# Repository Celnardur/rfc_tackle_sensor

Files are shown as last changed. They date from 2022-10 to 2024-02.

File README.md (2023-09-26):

# Collegiate Robotic Football Tackle Sensor Hardware

## Cloning the Repo

Open a git bash terminal in the directory of your choosing and call the following command:

`git clone https://github.com/Celnardur/rfc_tackle_sensor.git`

## Developing

This project was created using KiCad v6.  This must be installed prior to editing the project.

## Additional Links

- The firmware for the sensor can be found here: https://github.com/ehunck/rfc_tackle_sensor_firmware
- An example web-serial configuration utility can be found here: https://github.com/ehunck/tackle-sensor-utility

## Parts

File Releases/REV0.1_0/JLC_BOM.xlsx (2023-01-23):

Comment | Designator | Footprint | JLCPCB Part #（optional） | Quantity | MPN | Unit Price (@ qty 100) | Device Price
100nF, 50V | C1, C3, C4, C9, C13, C14 | Capacitor_SMD:C_0805_2012Metric | C49678 | 6 | CC0805KRX7R9BB104 | 0.0038 | 0.0228
10uF, 50V | C2, C15 | Capacitor_SMD:CP_Elec_6.3x5.8 | C308830 | 2 | UUD1H100MCL1GS | 0.0818 | 0.1636
2200pF,10%,50V | C5 | Capacitor_SMD:C_0402_1005Metric | C338130 | 1 | 0402B222K500CT | 0.0011 | 0.0011
0.22uF,10%,35V | C6 | Capacitor_SMD:C_0402_1005Metric | C694490 | 1 | CGA2B1X7R1V224KT000F | 0.0338 | 0.0338
1uF, 50V | C7, C10, C11 | Capacitor_SMD:C_0603_1608Metric | C90540 | 3 | 0603B105K500NT | 0.0096 | 0.0288
1nF, 50V | C8 | Capacitor_SMD:C_0402_1005Metric | C1523 | 1 | 0402B102K500NT | 0.001 | 0.001
22uF, 20V | C12 | Capacitor_SMD:CP_Elec_6.3x5.9 | C215761 | 1 | 20SVP22M | 0.3975 | 0.3975
BZT52-B15_R1_00001 | D1 | Diode_SMD:D_SOD-123 | C188533 | 1 | BZT52-B15_R1_00001 | 0.0173 | 0.0173
DSK34 | D2 | Diode_SMD:D_SOD-123F | C41029 | 1 | DSK34 | 0.0282 | 0.0282
LED | D3 | LED_SMD:LED_0603_1608Metric | C72038 | 1 | 19-213/Y2C-CQ2R2L/3T(CY) | 0.0159 | 0.0159
CLV1A-FKB-CK1VW1DE1BB7C3C3 | D4 | LED_SMD:LED_Cree-PLCC4_3.2x2.8mm_CCW |  | 1 | CLV1A-FKB-CK1VW1DE1BB7C3C3 | 0.361 | 0.361
1210L075YR | F1 | Resistor_SMD:R_1210_3225Metric | C207046 | 1 | 1210L075YR | 0.1673 | 0.1673
Conn_ARM_JTAG_SWD_10 | J1 | rfc_footprint_lib:20021121-00010C4LF | C150517 | 1 | 20021121-00010C4LF | 0.7533 | 0.7533
Conn_01x02_Male | J2 | Connector_JST:JST_XH_B2B-XH-A_1x02_P2.50mm_Vertical | C158012 | 1 | B2B-XH-A(LF)(SN) | 0.0257 | 0.0257
Conn_01x03_Male | J3 | Connector_JST:JST_XH_B3B-XH-A_1x03_P2.50mm_Vertical | C144394 | 1 | B3B-XH-A(LF)(SN) | 0.027 | 0.027
Conn_01x04_Male | J4 | Connector_JST:JST_XH_B4B-XH-A_1x04_P2.50mm_Vertical | C144395 | 1 | B4B-XH-A(LF)(SN) | 0.0344 | 0.0344
DMP4051LK3 | Q1 | Package_TO_SOT_SMD:TO-252-2 | C397952 | 1 | DMP4051LK3-13 | 0.363 | 0.363
NCE0110K | Q2 | Package_TO_SOT_SMD:TO-252-2 | C95272 | 1 | NCE0110K | 0.1314 | 0.1314
10k,1%,63mW | R1, R3, R5, R9 | Resistor_SMD:R_0402_1005Metric | C25744 | 4 | 0402WGF1002TCE | 0.0006 | 0.0024
634,.1%,63mW | R2 | Resistor_SMD:R_0402_1005Metric | C2998183 | 1 | FRC0402F6340TS | 0.0005 | 0.0005
56.2k,1%,63mW | R4 | Resistor_SMD:R_0402_1005Metric | C54968 | 1 | 0402WGF5622TCE | 0.0005 | 0.0005
100,1%,63mW | R6 | Resistor_SMD:R_0402_1005Metric | C25076 | 1 | 0402WGF1000TCE | 0.0005 | 0.0005
25mOhm,1%,500mW | R7 | Resistor_SMD:R_1206_3216Metric | C160920 | 1 | RL12FTNR200 | 0.0122 | 0.0122
84.5k,1%,63mW | R8 | Resistor_SMD:R_0402_1005Metric | C100545 | 1 | CR0402FF8452G | 0.0005 | 0.0005
0,63mW | R10 | Resistor_SMD:R_0402_1005Metric | C106231 | 1 | RC0402FR-070RL | 0.0007 | 0.0007
1k,1%,25mW | R11, R12, R13, R14 | Resistor_SMD:R_0603_1608Metric | C21190 | 4 | 0603WAF1001T5E | 0.0005 | 0.002
0,0.5W | R15, R17, R19 | Resistor_SMD:R_1210_3225Metric | C620661 | 3 | 1210W2F1000T5E | 0.0099 | 0.0297
220,1%,63mW | R16, R18 | Resistor_SMD:R_0402_1005Metric | C25091 | 2 | 0402WGF2200TCE | 0.0005 | 0.001
PTS645SL43SMTR92 LFS | SW1 | Button_Switch_SMD:SW_SPST_PTS645 | C221875 | 1 | PTS645SL43SMTR92LFS | 0.0741 | 0.0741
SW_DPDT_x2 | SW2 | rfc_footprint_lib:SS-3235S-L3 | C381098 | 1 | SS-3235S-L3 | 0.0617 | 0.0617
DRQ125-330-R | T1 | rfc_footprint_lib:DRQ125-150-R |  | 1 | DRQ125-330-R | 1.0832 | 1.0832
STM32G031Fx | U1 | Package_SO:TSSOP-20_4.4x6.5mm_P0.65mm | C529334 | 1 | STM32G031F8P6 | 0.9705 | 0.9705
LM3488 | U2 | Package_SO:VSSOP-8_3.0x3.0mm_P0.65mm | C80773 | 1 | LM3488MM/NOPB | 0.9 | 0.9
LIS2DE12 | U3 | Package_LGA:LGA-12_2x2mm_P0.5mm | C155639 | 1 | LIS2DE12TR | 1.017 | 1.017
LD1117S33TR_SOT223 | U4 | Package_TO_SOT_SMD:SOT-223-3_TabPin2 | C86781 | 1 | LD1117S33TR | 0.1982 | 0.1982
ULN2003ADR | U5 | Package_SO:SOIC-16_3.9x9.9mm_P1.27mm | C7512 | 1 | ULN2003ADR | 0.0918 | 0.0918
 |  |  |  |  |  | Total Price 1 unit | 7.0196

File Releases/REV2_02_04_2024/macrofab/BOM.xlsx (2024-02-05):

Designator | Value | Footprint | Populate | MPN | Manufacturer | MPN | Manufacturer
C1 | 100nF, 50V | C_0805_2012Metric | 1 | CC0805KRX7R9BB104 | Yageo
C10 | 1uF, 50V | C_0603_1608Metric | 1 | CL10A105KB8NNNC | Samsung
C11 | 1uF, 50V | C_0603_1608Metric | 1 | CL10A105KB8NNNC | Samsung
C12 | 22uF, 20V | CP_Elec_6.3x5.9 | 1 | 20SVP22M | Panasonic
C13 | 100nF, 50V | C_0805_2012Metric | 1 | CC0805KRX7R9BB104 | Yageo
C14 | 100nF, 50V | C_0805_2012Metric | 1 | CC0805KRX7R9BB104 | Yageo
C15 | 10uF, 50V | CP_Elec_6.3x5.8 | 1 | UUD1H100MCL1GS | Nichicon
C2 | 10uF, 50V | CP_Elec_6.3x5.8 | 1 | UUD1H100MCL1GS | Nichicon
C3 | 100nF, 50V | C_0805_2012Metric | 1 | CC0805KRX7R9BB104 | Yageo
C4 | 100nF, 50V | C_0805_2012Metric | 1 | CC0805KRX7R9BB104 | Yageo
C5 | 2200pF,10%,50V | C_0402_1005Metric | 1 | 0402B222K500CT | Walsin Technologies
C6 | 0.22uF,10%,35V | C_0402_1005Metric | 1 | CGA2B1X7R1V224KT000F | TDK | CGA2B1X7R1V224K050BE | TDK
C7 | 1uF, 50V | C_0603_1608Metric | 1 | CL10A105KB8NNNC | Samsung
C8 | 1nF, 50V | C_0402_1005Metric | 1 | 0402B102K500NT | Knowles Acoustics | C1005X7R1H102K050BA | TDK
C9 | 100nF, 50V | C_0805_2012Metric | 1 | CC0805KRX7R9BB104 | Yageo
D1 | BZT52-B15_R1_00001 | D_SOD-123 | 1 | BZT52-B15_R1_00001 | Panjit
D2 | DSK34 | D_SOD-123F | 1 | SBA340AL_R1_00001 | Panjit
D3 | LED | LED_0603_1608Metric | 1 | B1911UY--20D000114U1930 | Harvatek
D4 | CLV1A-FKB-CK1VW1DE1BB7C3C3 | LED_Cree-PLCC4_3.2x2.8mm_CCW | 1 | CLV1A-FKB-CK1VW1DE1BB7C3C3 | Wolfspeed
F1 | 1210L075YR | R_1210_3225Metric | 1 | 1210L075YR | Littelfuse
FID1 | Fiducial | Fiducial_0.5mm_Mask1.5mm | 0
FID2 | Fiducial | Fiducial_0.5mm_Mask1.5mm | 0
FID3 | Fiducial | Fiducial_0.5mm_Mask1.5mm | 0
H1 | MountingHole | MountingHole_3.2mm_M3 | 0
H2 | MountingHole | MountingHole_3.2mm_M3 | 0
H3 | MountingHole | MountingHole_3.2mm_M3 | 0
H4 | MountingHole | MountingHole_3.2mm_M3 | 0
J1 | Conn_ARM_JTAG_SWD_10 | 20021121-00010C4LF | 1 | 20021121-00010C4LF | Amphenol Communications Solutions
J2 | Conn_01x02_Male | JST_XH_B2B-XH-A_1x02_P2.50mm_Vertical | 1 | B2B-XH-A | JST
J4 | Conn_01x04_Male | JST_XH_B4B-XH-A_1x04_P2.50mm_Vertical | 1 | B4B-XH-A | JST
J5 | Conn_01x06_Male | JST_XH_B6B-XH-A_1x06_P2.50mm_Vertical | 1 | B6B-XH-A | JST
Q1 | DMP4051LK3 | TO-252-2 | 1 | DMP4051LK3-13 | Diodes Inc.
Q2 | NCE0110K | TO-252-2 | 1 | NCE0110K | Wuxi | RFD3055LESM9A | onsemi
R1 | 10k,1%,63mW | R_0402_1005Metric | 1 | 0402WGF1002TCE | Royal Ohm | RC0402FR-0710KP | Yageo
R10 | 10k,1%,63mW | R_0402_1005Metric | 1 | 0402WGF1002TCE | Royal Ohm | RC0402FR-0710KP | Yageo
R11 | 1k,1%,25mW | R_0603_1608Metric | 1 | 0603WAF1001T5E | Royal Ohm | RNCP0603FTD1K00 | Stackpole Electronics
R12 | 1k,1%,25mW | R_0603_1608Metric | 1 | 0603WAF1001T5E | Royal Ohm | RNCP0603FTD1K00 | Stackpole Electronics
R13 | 1k,1%,25mW | R_0603_1608Metric | 1 | 0603WAF1001T5E | Royal Ohm | RNCP0603FTD1K00 | Stackpole Electronics
R14 | 1k,1%,25mW | R_0603_1608Metric | 1 | 0603WAF1001T5E | Royal Ohm | RNCP0603FTD1K00 | Stackpole Electronics
R15 | 0,0.5W | R_1210_3225Metric | 1 | 1210W2F1000T5E | Uniroyal | RMCF1210ZT0R00 | Stackpole Electronics
R16 | 220,1%,63mW | R_0402_1005Metric | 1 | 0402WGF2200TCE | Royal Ohm | RC0402FR-07220RL | Yageo
R17 | 0,0.5W | R_1210_3225Metric | 1 | 1210W2F1000T5E | Uniroyal | RMCF1210ZT0R00 | Stackpole Electronics
R18 | 220,1%,63mW | R_0402_1005Metric | 1 | 0402WGF2200TCE | Royal Ohm | RC0402FR-07220RL | Yageo
R19 | 0,0.5W | R_1210_3225Metric | 1 | 1210W2F1000T5E | Uniroyal | RMCF1210ZT0R00 | Stackpole Electronics
R2 | 634,.1%,63mW | R_0402_1005Metric | 1 | RC0402FR-07634RL | Yageo
R20 | 220,1%,63mW | R_0402_1005Metric | 1 | 0402WGF2200TCE | Royal Ohm | RC0402FR-07220RL | Yageo
R21 | 10k,1%,63mW | R_0402_1005Metric | 1 | 0402WGF1002TCE | Royal Ohm | RC0402FR-0710KP | Yageo
R22 | 100k,1%,63mW | R_0402_1005Metric | 1 | RT0402BRE07100KL | Yageo
R23 | 10k,1%,63mW | R_0402_1005Metric | 1 | 0402WGF1002TCE | Royal Ohm | RC0402FR-0710KP | Yageo
R24 | 220,1%,63mW | R_0402_1005Metric | 1 | 0402WGF2200TCE | Royal Ohm | RC0402FR-07220RL | Yageo
R25 | 220,1%,63mW | R_0402_1005Metric | 1 | 0402WGF2200TCE | Royal Ohm | RC0402FR-07220RL | Yageo
R3 | 10k,1%,63mW | R_0402_1005Metric | 1 | 0402WGF1002TCE | Royal Ohm | RC0402FR-0710KP | Yageo
R4 | 56.2k,1%,63mW | R_0402_1005Metric | 1 | RC0402FR-0756K2L | Yageo
R5 | 100k,1%,63mW | R_0402_1005Metric | 1 | RT0402BRE07100KL | Yageo
R6 | 100,1%,63mW | R_0402_1005Metric | 1 | 0402WGF1000TCE | Royal Ohm | RC0402FR-13100RL | Yageo
R7 | 25mOhm,1%,500mW | R_1206_3216Metric | 1 | CSR1206FK25L0 | Stackpole Electronics
R8 | 84.5k,1%,63mW | R_0402_1005Metric | 1 | RC0402FR-0784K5L | Yageo
R9 | 10k,1%,63mW | R_0402_1005Metric | 1 | 0402WGF1002TCE | Royal Ohm | RC0402FR-0710KP | Yageo
S1 | DS01-254-L-02BE | SW_DS01-254-L-02BE | 1 | DS01-254-L-02BE | CUI Devices
SW1 | PTS645SL43SMTR92 LFS | SW_SPST_PTS645 | 1 | PTS645SL43SMTR92LFS | C&K Components
T1 | DRQ125-330-R | DRQ125-150-R | 1 | DRQ125-330-R | Eaton
TP1 | TestPoint | TestPoint_Pad_D1.0mm | 0
TP10 | TestPoint | test_point | 0
TP11 | TestPoint | test_point | 0
TP12 | TestPoint | TestPoint_Pad_D1.0mm | 0
TP13 | TestPoint | test_point | 0
TP14 | TestPoint | test_point | 0
TP15 | TestPoint | TestPoint_Pad_D1.0mm | 0
TP2 | TestPoint | test_point | 0
TP3 | TestPoint | TestPoint_Pad_D1.0mm | 0
TP8 | TestPoint | test_point | 0
TP9 | TestPoint | test_point | 0
U1 | STM32G031Fx | TSSOP-20_4.4x6.5mm_P0.65mm | 1 | STM32G031F8P6 | STMicroelectronics
U2 | LM3488 | VSSOP-8_3.0x3.0mm_P0.65mm | 1 | LM3488MM/NOPB | Texas Instruments
U3 | LIS2DE12 | LGA-12_2x2mm_P0.5mm | 1 | LIS2DE12TR | STMicroelectronics
U4 | LD1117S33TR_SOT223 | SOT-223-3_TabPin2 | 1 | LD1117S33TR | STMicroelectronics
U5 | ULN2003ADR | SOIC-16_3.9x9.9mm_P1.27mm | 1 | ULN2003ADR | Texas Instruments

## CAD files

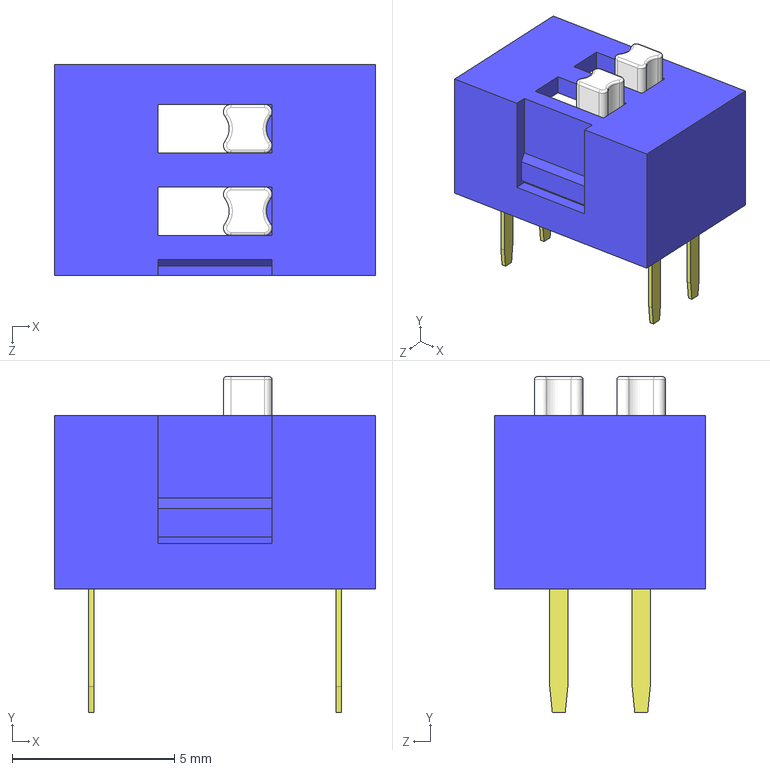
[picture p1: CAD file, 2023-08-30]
CUI_DEVICES_DS01-254-L-02BE.step
9.90 x 10.4 x 6.50 mm

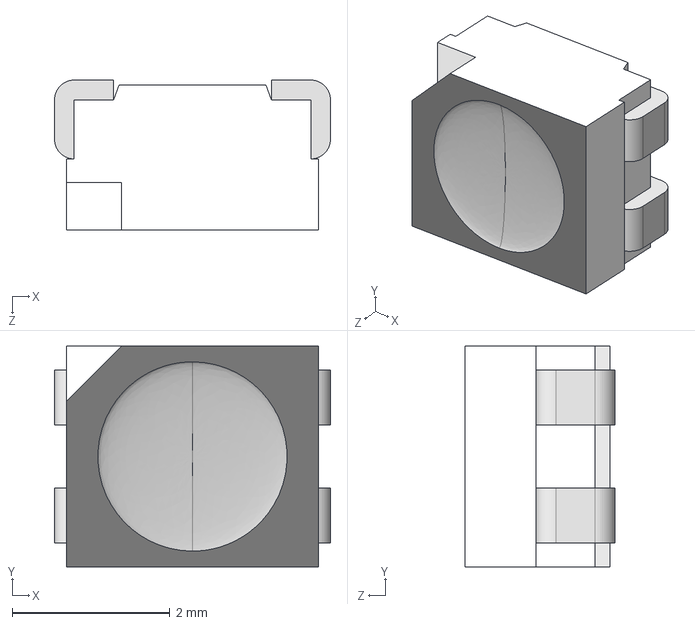
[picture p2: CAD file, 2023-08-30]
PLCC4_SMD_LED.STEP
3.50 x 2.80 x 1.90 mm

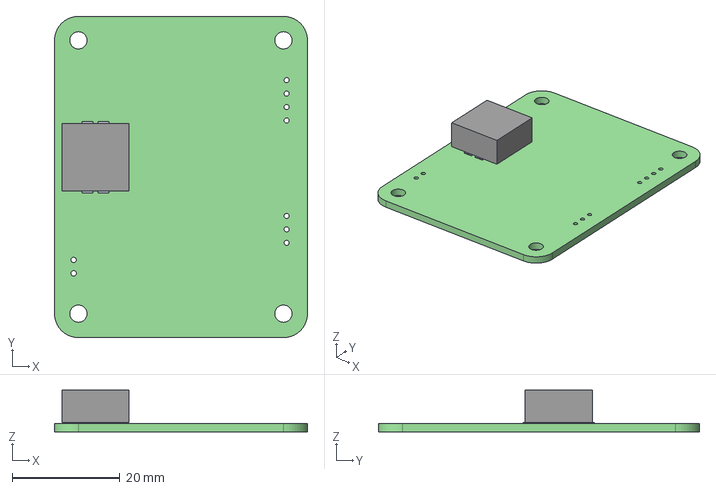
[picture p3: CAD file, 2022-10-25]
tackle_sensor_hardware.step
47.0 x 59.7 x 7.74 mm
tackle_sensor_hardware PCB

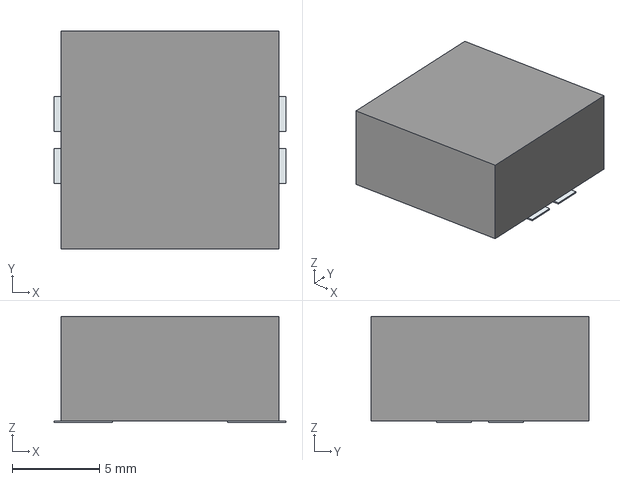
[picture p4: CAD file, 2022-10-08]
DRQ125-330-R.stp
13.3 x 12.5 x 6.10 mm
Pins

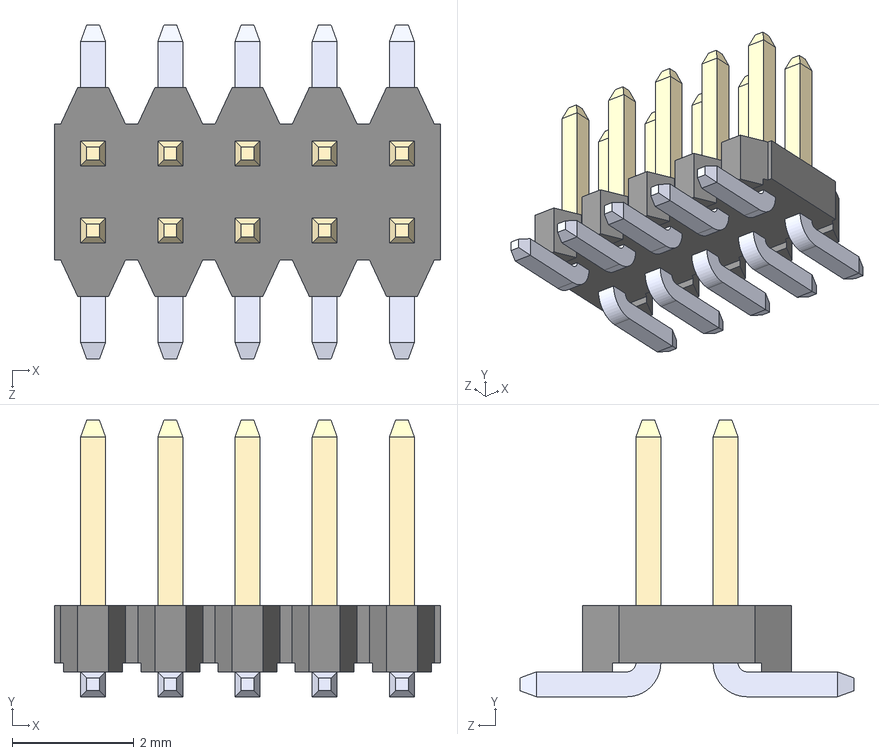
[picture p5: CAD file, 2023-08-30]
20021121-00010C4LF--3DModel-STEP-56544.STEP
6.35 x 4.55 x 5.50 mm
20021121-additional body-goldtin_5
Pin^20021121-additional-goldtin x 5

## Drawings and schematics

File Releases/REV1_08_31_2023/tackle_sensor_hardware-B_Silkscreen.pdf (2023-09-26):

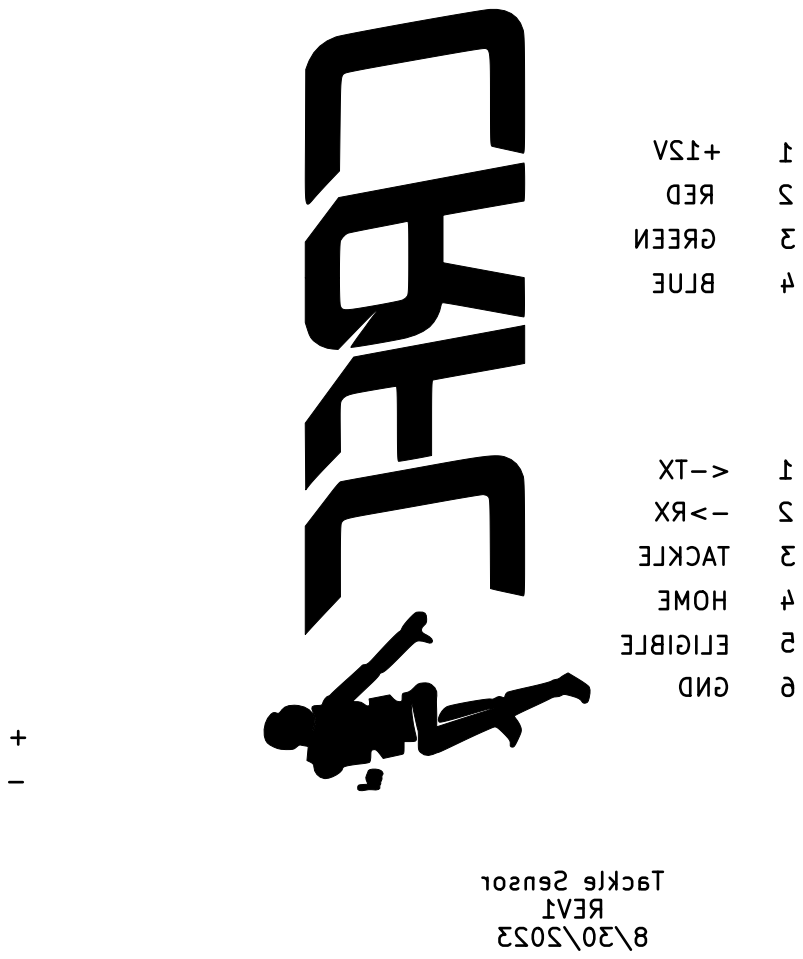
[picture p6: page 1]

8/30/2023 3 TACKLE 63 +- 2 +12V GREEN 24 ELIGIBLE 51 RED

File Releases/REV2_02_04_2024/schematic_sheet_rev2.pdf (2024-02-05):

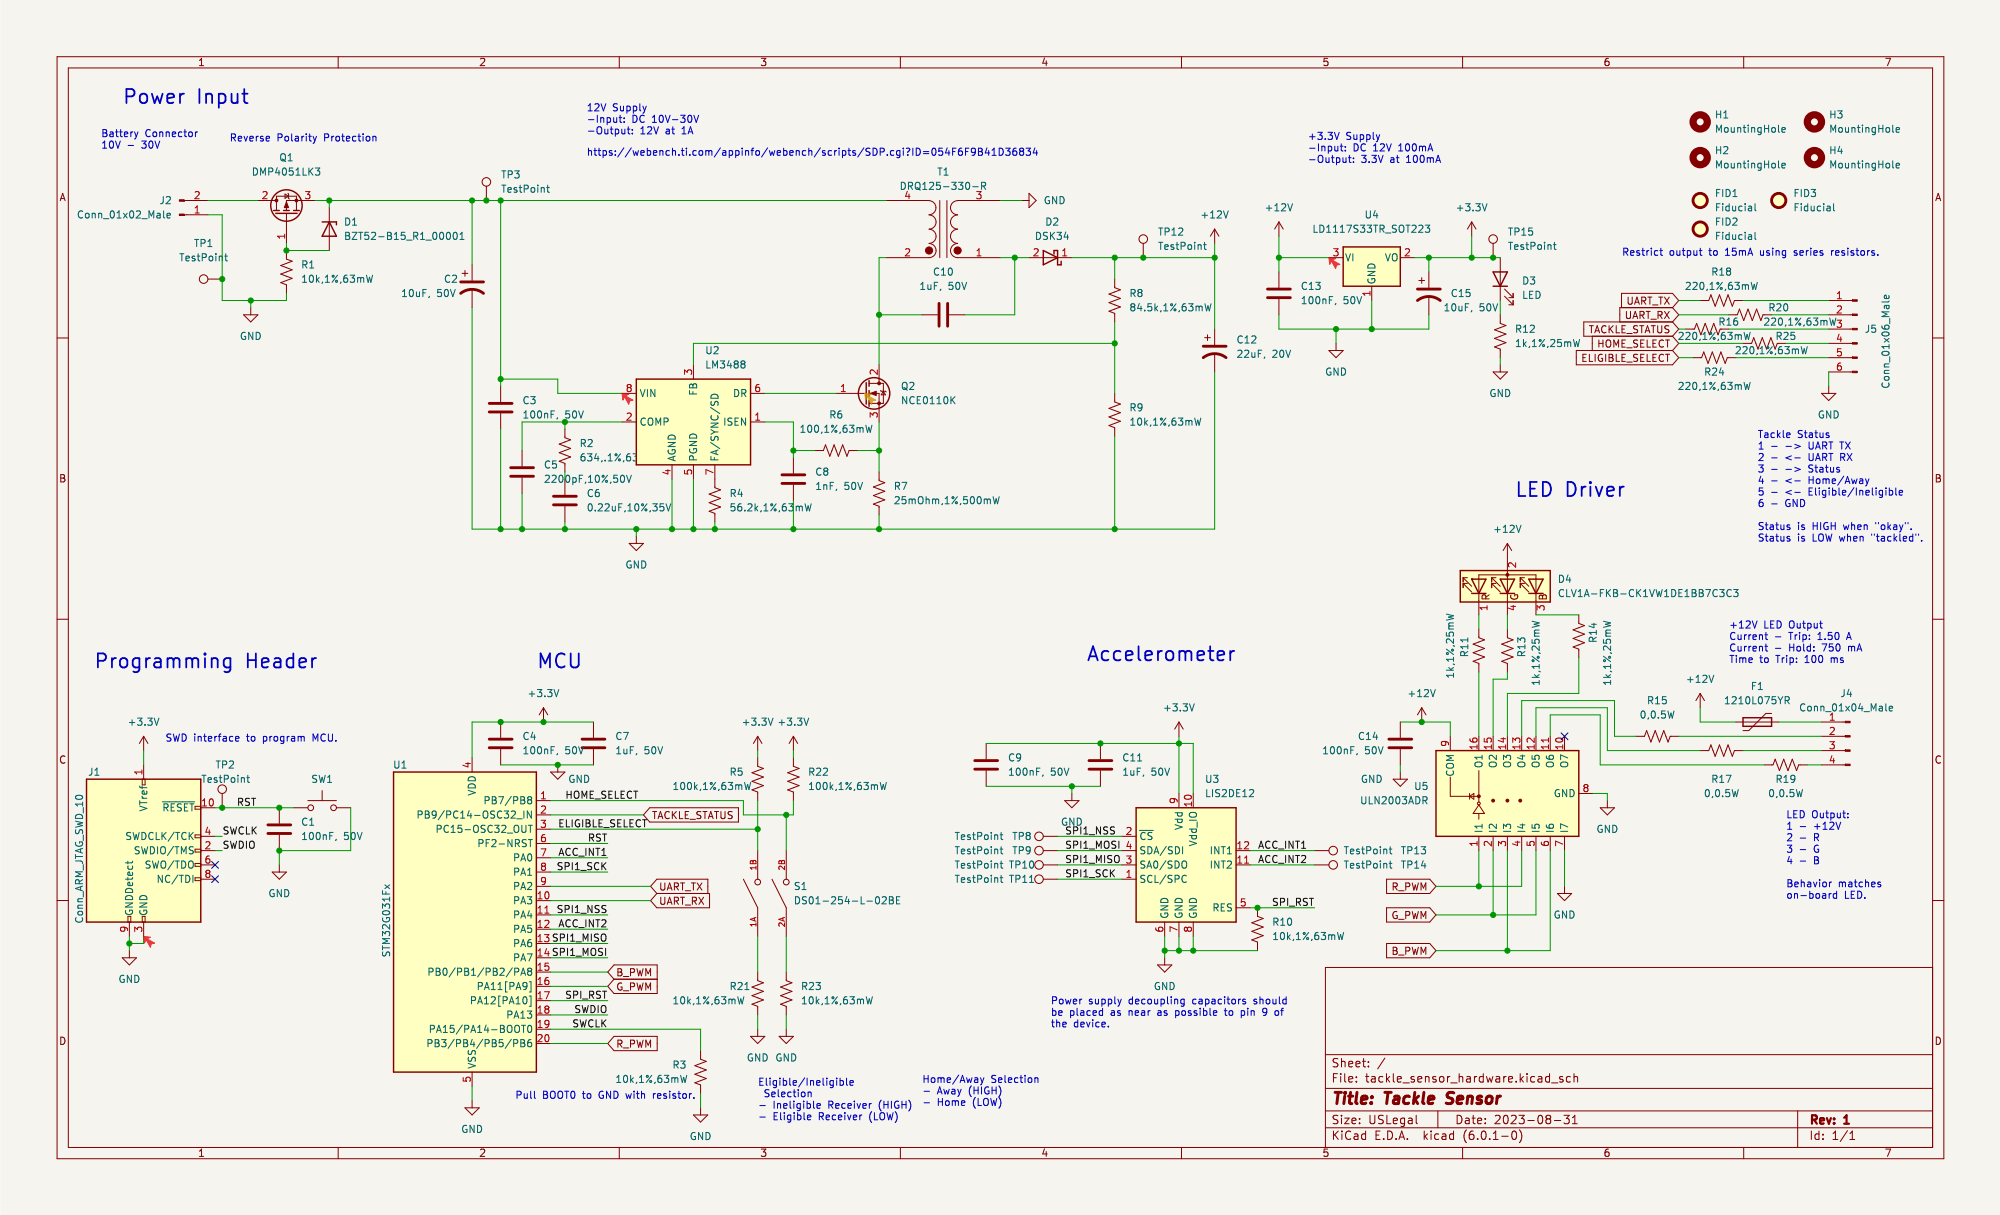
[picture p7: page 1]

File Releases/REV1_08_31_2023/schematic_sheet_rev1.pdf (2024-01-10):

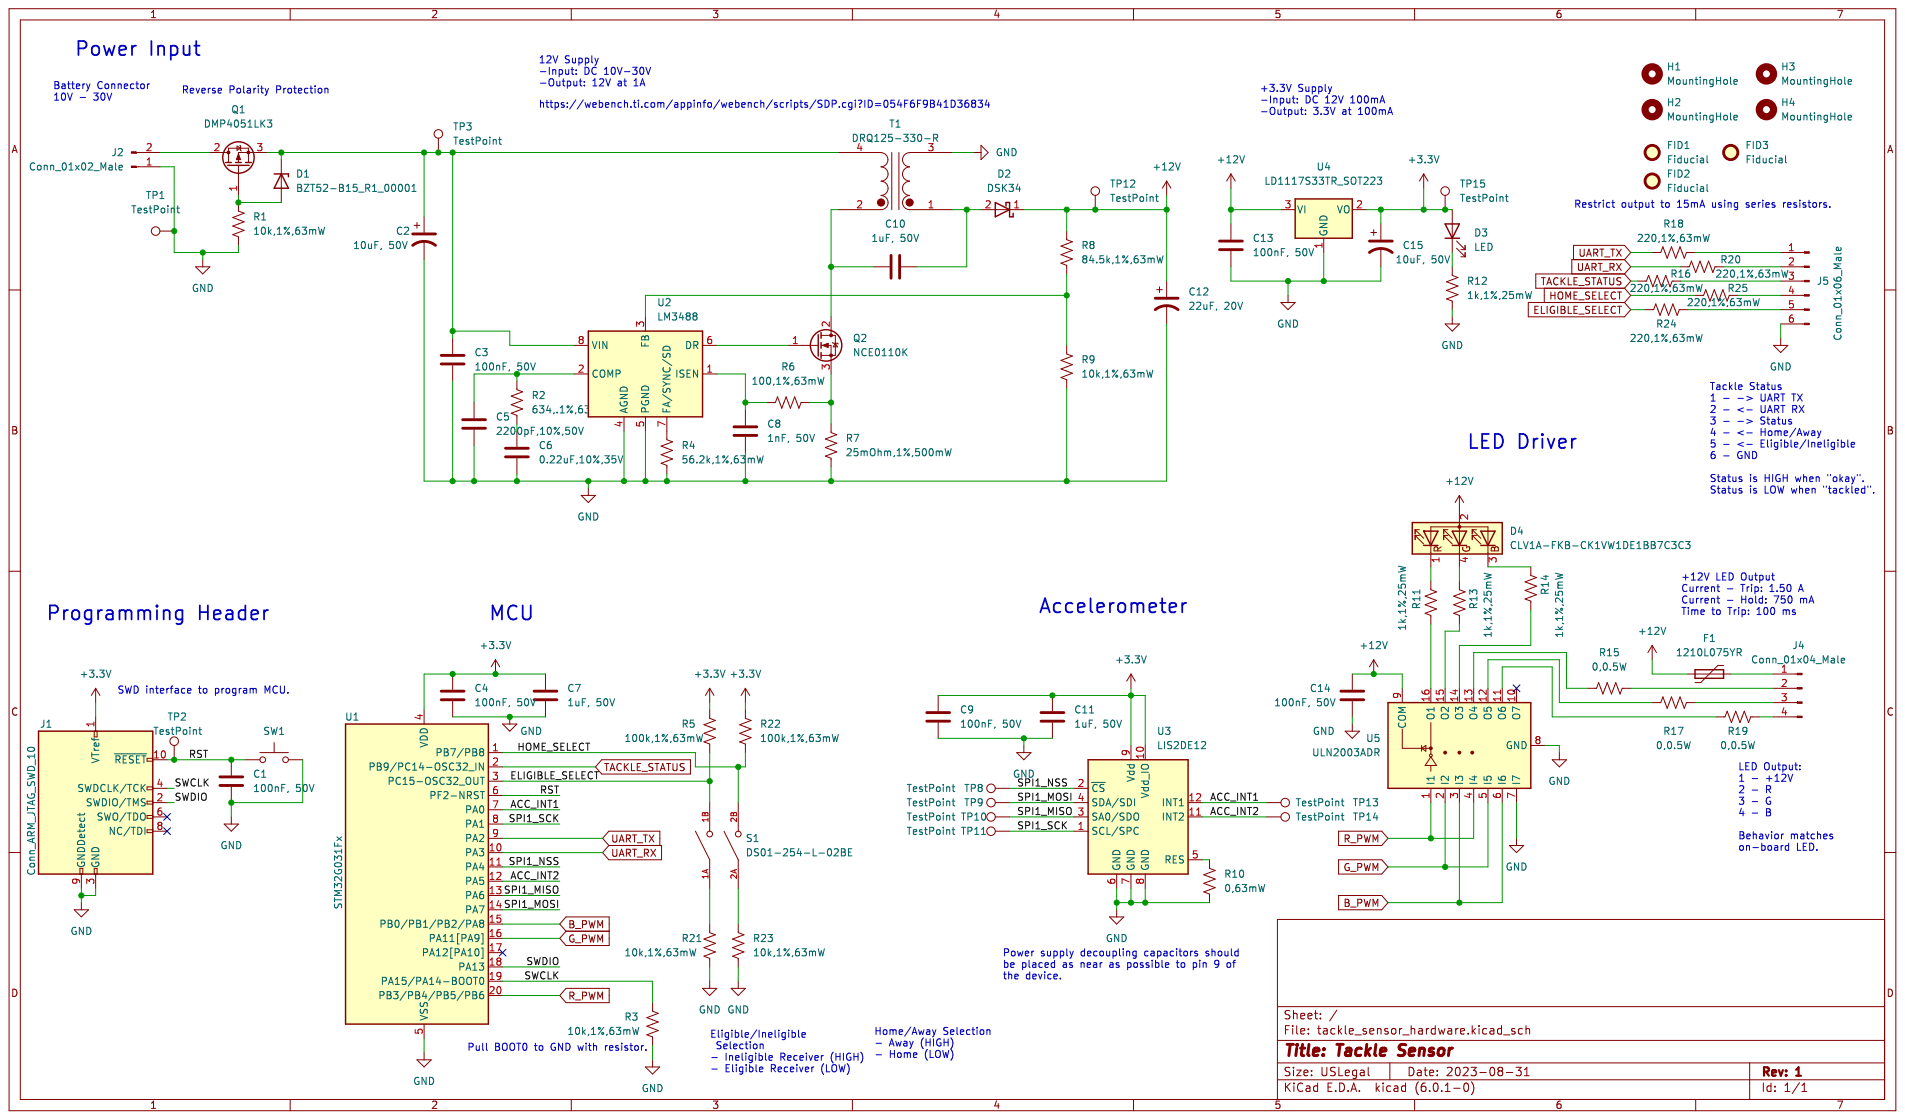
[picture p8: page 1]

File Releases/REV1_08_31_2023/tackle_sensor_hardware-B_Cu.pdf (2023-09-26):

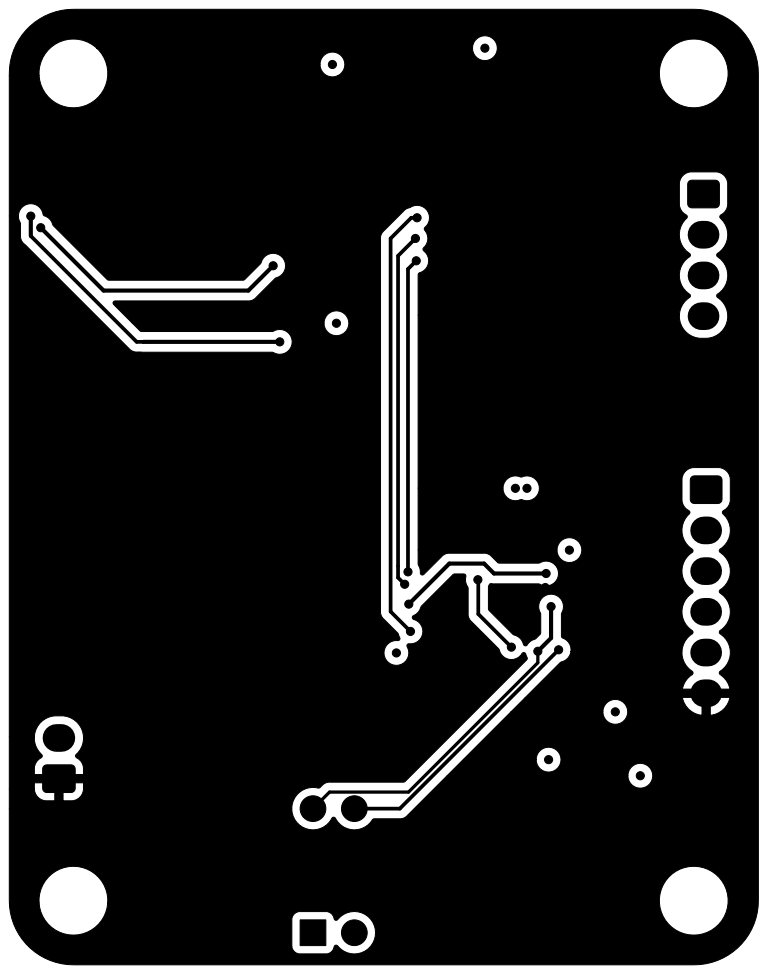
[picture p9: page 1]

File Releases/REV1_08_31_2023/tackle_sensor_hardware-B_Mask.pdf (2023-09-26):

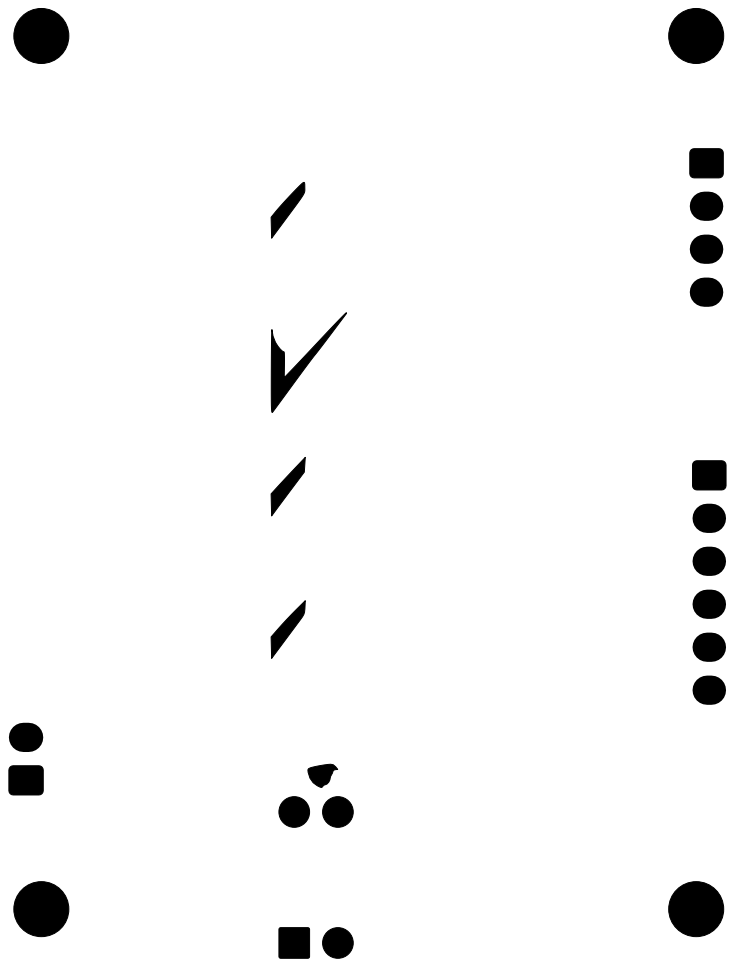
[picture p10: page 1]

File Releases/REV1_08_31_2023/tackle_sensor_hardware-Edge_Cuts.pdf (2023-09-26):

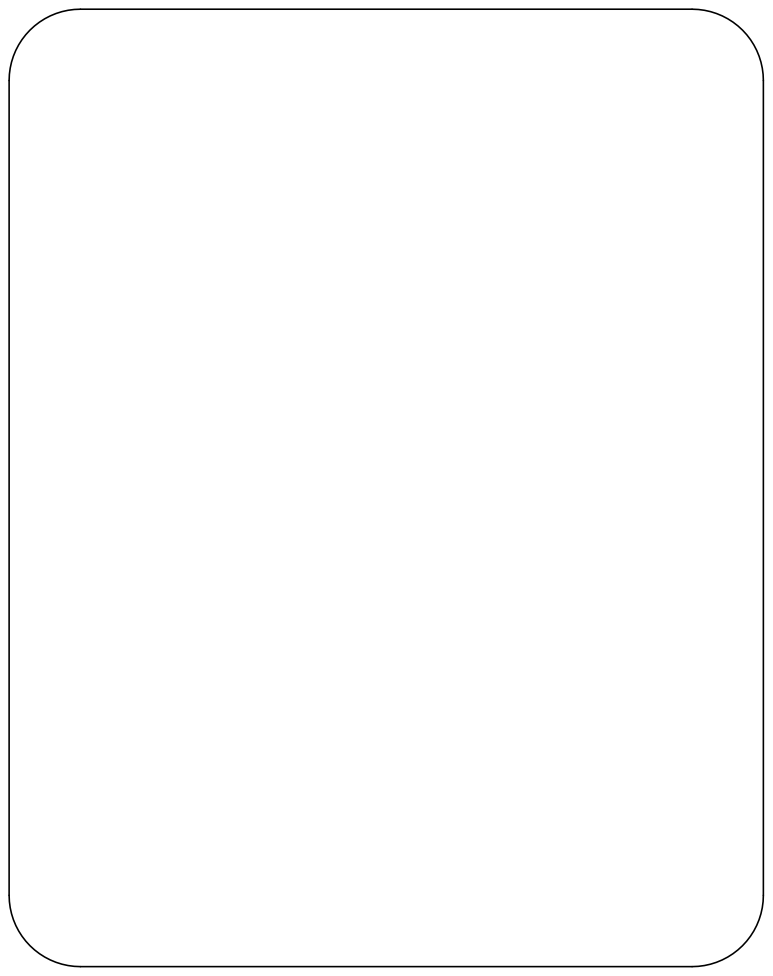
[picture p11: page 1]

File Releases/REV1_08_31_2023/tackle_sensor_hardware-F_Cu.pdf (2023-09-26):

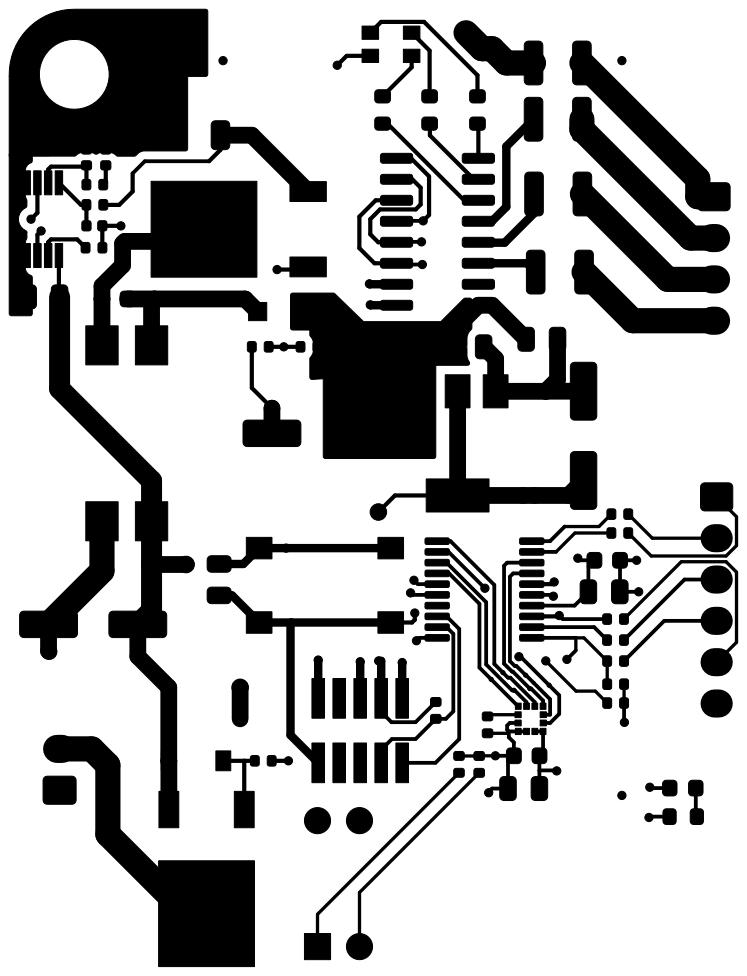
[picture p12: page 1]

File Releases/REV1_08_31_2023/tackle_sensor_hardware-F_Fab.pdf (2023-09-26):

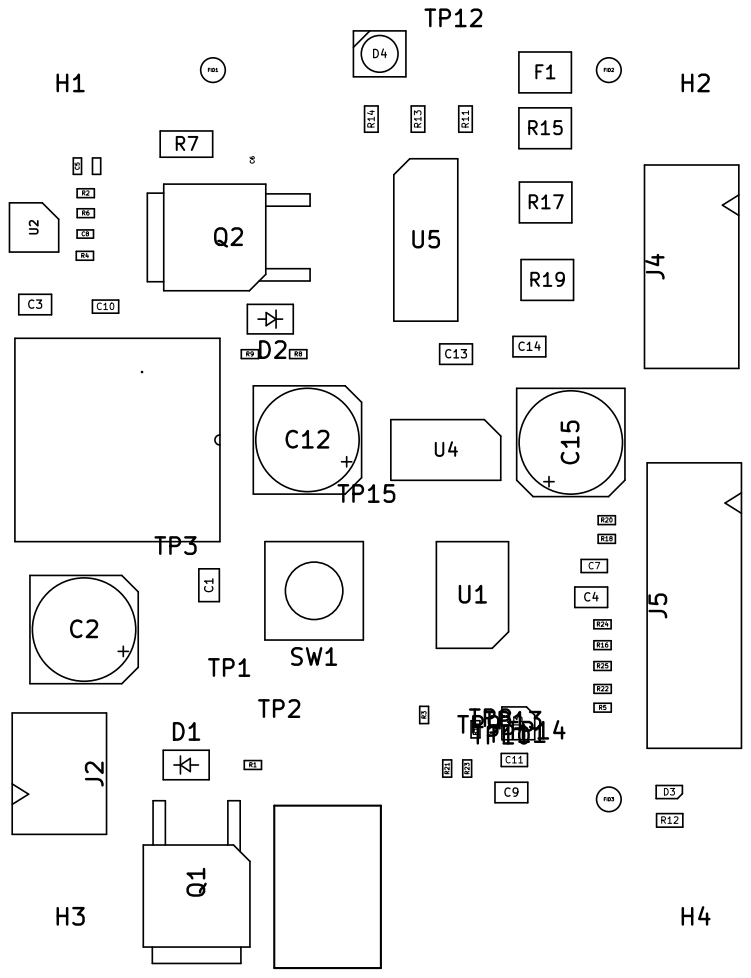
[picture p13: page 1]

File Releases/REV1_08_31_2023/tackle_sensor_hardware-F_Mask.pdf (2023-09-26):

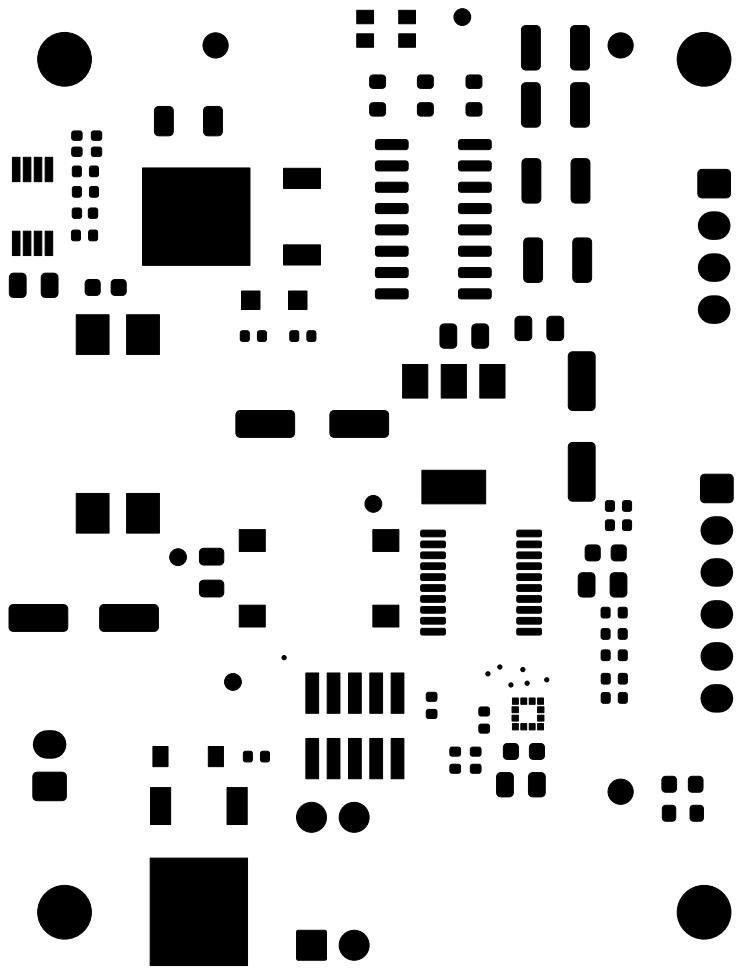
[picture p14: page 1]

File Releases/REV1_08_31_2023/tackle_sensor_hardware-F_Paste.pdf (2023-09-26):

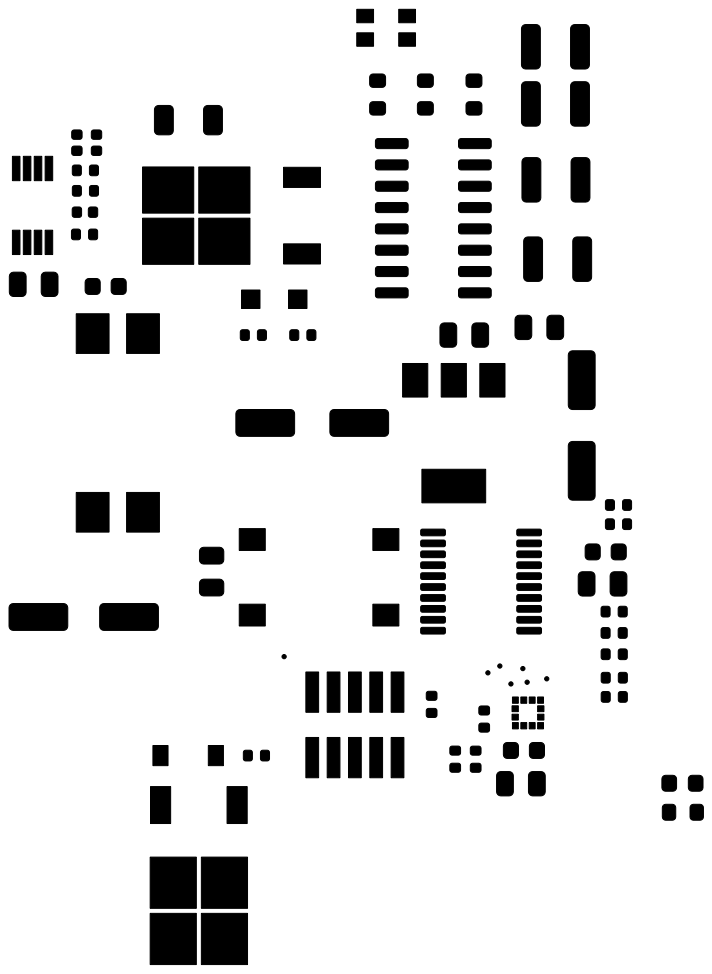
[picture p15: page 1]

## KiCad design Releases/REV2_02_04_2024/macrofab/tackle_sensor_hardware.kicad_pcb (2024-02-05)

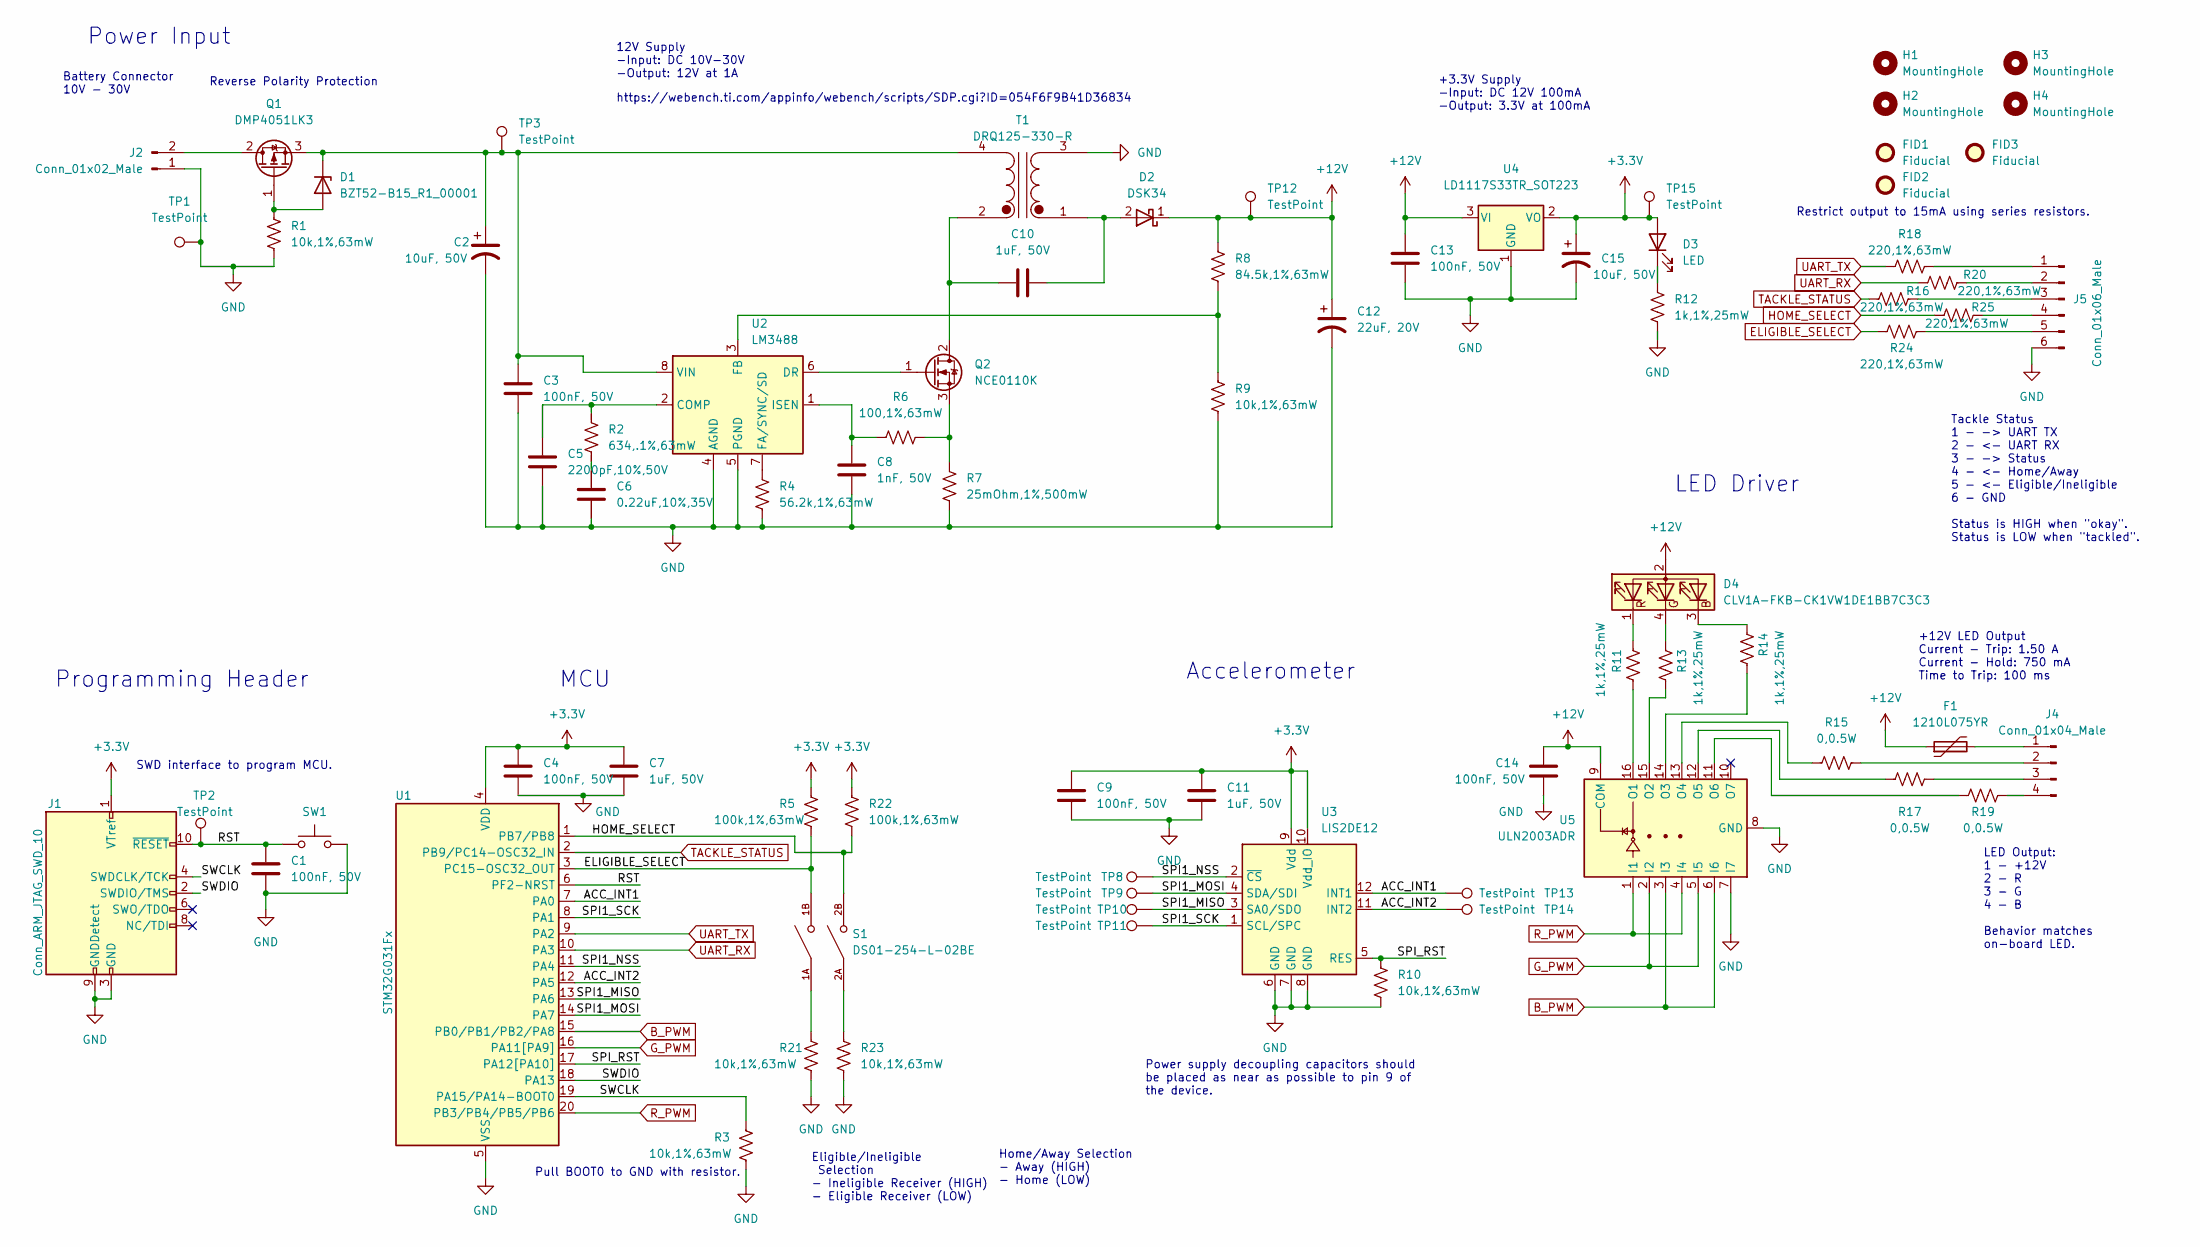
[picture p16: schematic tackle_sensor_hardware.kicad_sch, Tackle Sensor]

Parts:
C1, C3, C4, C9, C13, C14: 100nF, 50V; C_0805_2012Metric; MPN CC0805KRX7R9BB104; JLCPN C49678
C2, C15: 10uF, 50V; CP_Elec_6.3x5.8; MPN UUD1H100MCL1GS; JLCPN C308830
C5: 2200pF,10%,50V; C_0402_1005Metric; MPN 0402B222K500CT; JLCPN C338130
C6: 0.22uF,10%,35V; C_0402_1005Metric; MPN CGA2B1X7R1V224KT000F; JLCPN C694490
C7, C10, C11: 1uF, 50V; C_0603_1608Metric; MPN 0603B105K500NT; JLCPN C90540
C8: 1nF, 50V; C_0402_1005Metric; MPN 0402B102K500NT; JLCPN C1523
C12: 22uF, 20V; CP_Elec_6.3x5.9; MPN 20SVP22M; JLCPN C215761
D1: BZT52-B15_R1_00001; D_SOD-123; MPN BZT52-B15_R1_00001; JLCPN C188533
D2: DSK34; D_SOD-123F; MPN DSK34; JLCPN C41029
D3: LED; LED_0603_1608Metric; MPN 19-213/Y2C-CQ2R2L/3T(CY); JLCPN C72038
D4: CLV1A-FKB-CK1VW1DE1BB7C3C3; LED_Cree-PLCC4_3.2x2.8mm_CCW
F1: 1210L075YR; R_1210_3225Metric; MPN 1210L075YR; JLCPN C207046
FID1, FID2, FID3: Fiducial; Fiducial_0.5mm_Mask1.5mm
H1, H2, H3, H4: MountingHole; MountingHole_3.2mm_M3
J1: Conn_ARM_JTAG_SWD_10; 20021121-00010C4LF; MPN 20021121-00010C4LF; JLCPN C150517
J2: Conn_01x02_Male; JST_XH_B2B-XH-A_1x02_P2.50mm_Vertical; MPN B2B-XH-A(LF)(SN); JLCPN C158012
J4: Conn_01x04_Male; JST_XH_B4B-XH-A_1x04_P2.50mm_Vertical; MPN B4B-XH-A(LF)(SN); JLCPN C144395
J5: Conn_01x06_Male; JST_XH_B6B-XH-A_1x06_P2.50mm_Vertical
Q1: DMP4051LK3; TO-252-2; MPN DMP4051LK3-13; JLCPN C397952
Q2: NCE0110K; TO-252-2; MPN NCE0110K; JLCPN C95272
R1, R3, R9, R10, R21, R23: 10k,1%,63mW; R_0402_1005Metric; MPN 0402WGF1002TCE; JLCPN C25744
R2: 634,.1%,63mW; R_0402_1005Metric; MPN FRC0402F6340TS; JLCPN C2998183
R4: 56.2k,1%,63mW; R_0402_1005Metric; MPN 0402WGF5622TCE; JLCPN C54968
R5, R22: 100k,1%,63mW; R_0402_1005Metric
R6: 100,1%,63mW; R_0402_1005Metric; MPN 0402WGF1000TCE; JLCPN C25076
R7: 25mOhm,1%,500mW; R_1206_3216Metric; MPN RL12FTNR200; JLCPN C160920
R8: 84.5k,1%,63mW; R_0402_1005Metric; MPN CR0402FF8452G; JLCPN C100545
R11, R12, R13, R14: 1k,1%,25mW; R_0603_1608Metric; MPN 0603WAF1001T5E; JLCPN C21190
R15, R17, R19: 0,0.5W; R_1210_3225Metric; MPN 1210W2F1000T5E; JLCPN C620661
R16, R18, R20, R24, R25: 220,1%,63mW; R_0402_1005Metric; MPN 0402WGF2200TCE; JLCPN C25091
S1: DS01-254-L-02BE; SW_DS01-254-L-02BE; PARTREV 1.0
SW1: PTS645SL43SMTR92 LFS; SW_SPST_PTS645; MPN PTS645SL43SMTR92LFS; JLCPN C221875
T1: DRQ125-330-R; DRQ125-150-R; MPN DRQ125-330-R
TP1, TP3, TP12, TP15: TestPoint; TestPoint_Pad_D1.0mm
TP2, TP8, TP9, TP10, TP11, TP13, TP14: TestPoint; test_point
U1: STM32G031Fx; TSSOP-20_4.4x6.5mm_P0.65mm; MPN STM32G031F8P6; JLCPN C529334
U2: LM3488; VSSOP-8_3.0x3.0mm_P0.65mm; MPN LM3488MM/NOPB; JLCPN C80773
U3: LIS2DE12; LGA-12_2x2mm_P0.5mm; MPN LIS2DE12TR; JLCPN C155639
U4: LD1117S33TR_SOT223; SOT-223-3_TabPin2; MPN LD1117S33TR; JLCPN C86781
U5: ULN2003ADR; SOIC-16_3.9x9.9mm_P1.27mm; MPN ULN2003ADR; JLCPN C7512

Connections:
+3V3: C4.1, C7.1, C9.1, C11.1, C15.1, D3.2 (A), J1.1 (VTref), R5.1, R22.1, TP15.1, U1.4 (VDD), U3.9 (Vdd), U3.10 (Vdd_IO), U4.2 (VO)
+12V: C12.1, C13.1, C14.1, D2.1 (K), D4.2 (RK), F1.1, R8.1, TP12.1, U4.3 (VI), U5.9 (COM)
/ACC_INT1: TP13.1, U1.7 (PA0), U3.12 (INT1)
/ACC_INT2: TP14.1, U1.12 (PA5), U3.11 (INT2)
/RST: C1.1, J1.10 (~RESET), SW1.1, TP2.1, U1.6 (PF2-NRST)
/SPI1_MISO: TP10.1, U1.13 (PA6), U3.3 (SA0/SDO)
/SPI1_MOSI: TP9.1, U1.14 (PA7), U3.4 (SDA/SDI)
/SPI1_NSS: TP8.1, U1.11 (PA4), U3.2 (~CS)
/SPI1_SCK: TP11.1, U1.8 (PA1), U3.1 (SCL/SPC)
/SPI_RST: R10.1, U1.17 (PA12[PA10]), U3.5 (RES)
/SWCLK: J1.4 (SWDCLK/TCK), R3.2, U1.19 (PA15/PA14-BOOT0)
/SWDIO: J1.2 (SWDIO/TMS), U1.18 (PA13)
B_PWM: U1.15 (PB0/PB1/PB2/PA8), U5.3 (I3), U5.6 (I6)
ELIGIBLE_SELECT: R5.2, R24.1, S1.1B, U1.3 (PC15-OSC32_OUT)
GND: C1.2, C2.2, C3.2, C4.2, C5.2, C6.2, C7.2, C8.2, C9.2, C11.2, C12.2, C13.2, C14.2, C15.2, J1.3 (GND), J1.5 (GND), J1.9 (GNDDetect), J2.1, J5.6, R1.2, R3.1, R4.2, R7.2, R9.2, R10.2, R12.2, R21.2, R23.2, SW1.2, T1.3 (SA), TP1.1, U1.5 (VSS), U2.4 (AGND), U2.5 (PGND), U3.6 (GND), U3.7 (GND), U3.8 (GND), U4.1 (GND), U5.7 (I7), U5.8 (GND)
G_PWM: U1.16 (PA11[PA9]), U5.2 (I2), U5.5 (I5)
HOME_SELECT: R22.2, R25.1, S1.2B, U1.1 (PB7/PB8)
unnamed: C2.1, C3.1, D1.1 (K), Q1.3 (S), T1.4 (SB), TP3.1, U2.8 (VIN)
unnamed: C5.1, R2.1, U2.2 (COMP)
unnamed: C6.1, R2.2
unnamed: C8.1, R6.1, U2.1 (ISEN)
unnamed: C10.1, D2.2 (A), T1.1 (AA)
unnamed: D1.2 (A), Q1.1 (G), R1.1
unnamed: D3.1 (K), R12.1
unnamed: D4.1 (A), R11.1
unnamed: D4.3 (GK), R14.1
unnamed: D4.4 (BK), R13.1
unnamed: F1.2, J4.1
unnamed: J2.2, Q1.2 (D)
unnamed: J4.2, R15.1
unnamed: J4.3, R17.1
unnamed: J4.4, R19.1
unnamed: J5.1, R18.2
unnamed: J5.2, R20.2
unnamed: J5.3, R16.2
unnamed: J5.4, R25.2
unnamed: J5.5, R24.2
unnamed: Q2.1 (G), U2.6 (DR)
unnamed: R4.1, U2.7 (FA/SYNC/SD)
unnamed: R8.2, R9.1, U2.3 (FB)
unnamed: R11.2, U5.16 (O1)
unnamed: R13.2, U5.15 (O2)
unnamed: R14.2, U5.14 (O3)
unnamed: R15.2, U5.13 (O4)
unnamed: R17.2, U5.12 (O5)
unnamed: R19.2, U5.11 (O6)
unnamed: R21.1, S1.1A
unnamed: R23.1, S1.2A
R_PWM: U1.20 (PB3/PB4/PB5/PB6), U5.1 (I1), U5.4 (I4)
TACKLE_STATUS: R16.1, U1.2 (PB9/PC14-OSC32_IN)
UART_RX: R20.1, U1.10 (PA3)
UART_TX: R18.1, U1.9 (PA2)

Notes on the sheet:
Programming Header
Eligible/Ineligible Selection - Ineligible Receiver (HIGH) - Eligible Receiver (LOW)
LED Driver
12V Supply -Input: DC 10V-30V -Output: 12V at 1A
Home/Away Selection - Away (HIGH) - Home (LOW)
+12V LED Output Current - Trip: 1.50 A Current - Hold: 750 mA Time to Trip: 100 ms
+3.3V Supply -Input: DC 12V 100mA -Output: 3.3V at 100mA
Power Input
Tackle Status 1 - -> UART TX 2 - <- UART RX 3 - -> Status 4 - <- Home/Away 5 - <- Eligible/Ineligible 6 - GND Status is HIGH when "okay". Status is LOW when "tackled".
LED Output: 1 - +12V 2 - R 3 - G 4 - B Behavior matches on-board LED.
Pull BOOT0 to GND with resistor.
Battery Connector 10V - 30V
SWD interface to program MCU.
Restrict output to 15mA using series resistors.
MCU
Reverse Polarity Protection
Accelerometer
https://webench.ti.com/appinfo/webench/scripts/SDP.cgi?ID=054F6F9B41D36834
Power supply decoupling capacitors should be placed as near as possible to pin 9 of the device.

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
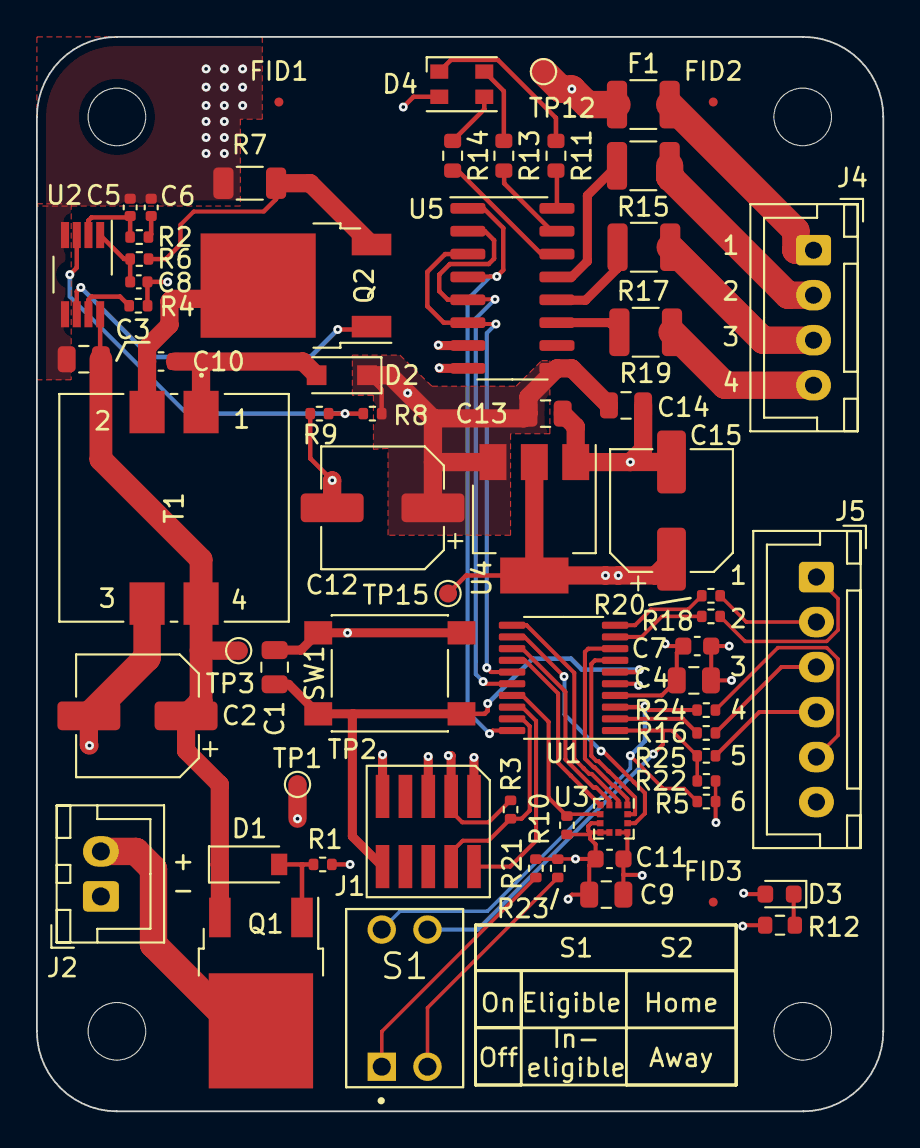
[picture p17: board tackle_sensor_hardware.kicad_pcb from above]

Board: 4 copper layers, 47.0 x 59.7 mm, 77 parts (0 on the bottom side), 54 nets.

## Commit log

2022-04-10 Set up KiCad Project
    [tackle_sensor_hardware.kicad_pcb, tackle_sensor_hardware.kicad_sch]
2022-04-10 (WIP) added some components and basic schematic pieces.
    [tackle_sensor_hardware.kicad_pcb, tackle_sensor_hardware.kicad_sch]
2022-04-10 (WIP) added prog header to schematic and added some WIP notes.
    [tackle_sensor_hardware.kicad_pcb, tackle_sensor_hardware.kicad_sch]
2022-04-10 added mounting holes
    [tackle_sensor_hardware.kicad_pcb, tackle_sensor_hardware.kicad_sch]
2022-04-10 added on-board LEDs
    [tackle_sensor_hardware.kicad_pcb, tackle_sensor_hardware.kicad_sch]
2022-04-11 updated connectors, added 0 ohm resistors
    [tackle_sensor_hardware.kicad_pcb, tackle_sensor_hardware.kicad_sch]
2022-04-11 added pinout to MCU
    [tackle_sensor_hardware.kicad_pcb, tackle_sensor_hardware.kicad_sch]
2022-04-12 added eFuse, added mosfet, added footprints
    [tackle_sensor_hardware.kicad_pcb, tackle_sensor_hardware.kicad_sch]
2022-04-13 Picked most RC components and footprints
    [tackle_sensor_hardware.kicad_pcb, tackle_sensor_hardware.kicad_sch]
2022-04-13 add graphic
    [tackle_sensor_hardware.kicad_pcb]
2022-04-15 updated component placement and board size, cleaning up schamtic and part selection.
    [tackle_sensor_hardware.kicad_pcb, tackle_sensor_hardware.kicad_sch]
2022-04-15 routing in progress.
    [tackle_sensor_hardware.kicad_pcb, tackle_sensor_hardware.kicad_sch]
2022-04-15 update reset button, add decoupling caps for MCU.
    [tackle_sensor_hardware.kicad_pcb, tackle_sensor_hardware.kicad_sch]
2022-04-16 added PTC
    [tackle_sensor_hardware.kicad_pcb, tackle_sensor_hardware.kicad_sch]
2022-04-18 route board
    [tackle_sensor_hardware.kicad_pcb]
2022-04-19 finish route, add release pacakage
    [tackle_sensor_hardware-B_Cu.gbl, tackle_sensor_hardware-B_Mask.gbs, tackle_sensor_hardware-B_Paste.gbp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]
2022-04-19 add BOM
2022-08-07 updated some parts with instock components
    [tackle_sensor_hardware.kicad_sch]
2022-09-01 Updating schematic and layout for manufacture with LCSC.
    [tackle_sensor_hardware.kicad_pcb, tackle_sensor_hardware.kicad_sch]
2022-10-08 updating the BOM
    [DRQ125-330-R.stp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]
2022-10-23 rerouted PCB after changes
    [tackle_sensor_hardware.kicad_pcb, tackle_sensor_hardware.kicad_sch, tackle_sensor_hardware.step]
2022-10-25 adding release v0.1
    [JLC_BOM.xlsx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]
2023-01-23 - updates for release v0.1
    [JLC_BOM.xlsx, JLC_BOM_v0.1.xlsx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]
2023-03-04 - add reference PDFs and dimensions to the layout
    [tackle_sensor_hardware.kicad_pcb]
2023-03-04 - change page size to legal
    [tackle_sensor_hardware.kicad_pcb]
2023-03-04 - added additional notes to the reference_sheet and the schematic sheet
    [tackle_sensor_hardware.kicad_pcb, tackle_sensor_hardware.kicad_sch]
2023-03-04 - update cable assembly link
    [tackle_sensor_hardware.kicad_pcb]
2023-08-30 - update PCB and schematic with new switch plus added 3d models
    [20021121-00010C4LF--3DModel-STEP-56544.STEP, CUI_DEVICES_DS01-254-L-02BE.step, PLCC4_SMD_LED.STEP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]
2023-08-31 - finish routing
    [tackle_sensor_hardware.kicad_pcb, tackle_sensor_hardware.kicad_sch]
2023-09-01 - updating layout and releasing
    [JLC_BOM.xlsx, JLC_BOM_v0.1.xlsx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]
2023-09-26 - release artifacts
    [JLC_BOM.xlsx, PCBFABEXP_BOM.xlsx, r2qr0hq.xlsx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]
2024-01-10 - regen. schematic with Logic level updates
    [tackle_sensor_hardware.kicad_sch]
2024-02-05 - Change SPI RST to pull down to 10k. Added line from MCU to toggle the ACCEL reset. Added release files REV2
    [BOM.xlsx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]

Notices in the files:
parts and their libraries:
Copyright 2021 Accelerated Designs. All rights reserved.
